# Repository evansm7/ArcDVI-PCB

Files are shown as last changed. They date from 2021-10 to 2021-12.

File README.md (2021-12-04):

# ArcDVI VIDC adapter PCBs
30 November 2021

Two PCBs used in the [ArcDVI](https://github.com/evansm7/ArcDVI) project.

These PCBs (#1 and #2) both perform the task of physical interfacing to an Acorn Archimedes VIDC chip, but for different machines.  PCB #1 is an interposer for VIDC-socketed machines (such as A440), which plugs into the VIDC socket and carries a socket for the VIDC.  PCB #2 uses an upturned through-hole PLCC socket to clip around a soldered VIDC (in machines such as A3000).

[vidc_interposer1 schematic](doc/vidc_interposer1.pdf), [vidc_interposer1 board](doc/vidc_interposer1_brd.pdf), [vidc_interposer2 schematic](doc/vidc_interposer2-PTH.pdf),
[vidc_interposer2 board](doc/vidc_interposer2-PTH_brd.pdf)

It was originally hoped that PCB #1 could be used on an A3000 too, with an SMT PLCC socket on the bottom (and nothing mounted on the top).  Those sockets are shallow, and the board level is then too low to clear surrounding components.  (Note there are two odd holes in the board; this was to clear some jumper headers.  These were unnecessarily carried into PCB #2's layout too.  In short, neither board needs these holes anymore.)

A separate project (TBD) is recreating PLCC socket-to-socket interface "blocks", enabling a PLCC socket (rather than plug) to be used on the underside of board #1.

The PCBs are designed in Eagle.

Copyright 2021 Matt Evans

CC BY-SA 3.0

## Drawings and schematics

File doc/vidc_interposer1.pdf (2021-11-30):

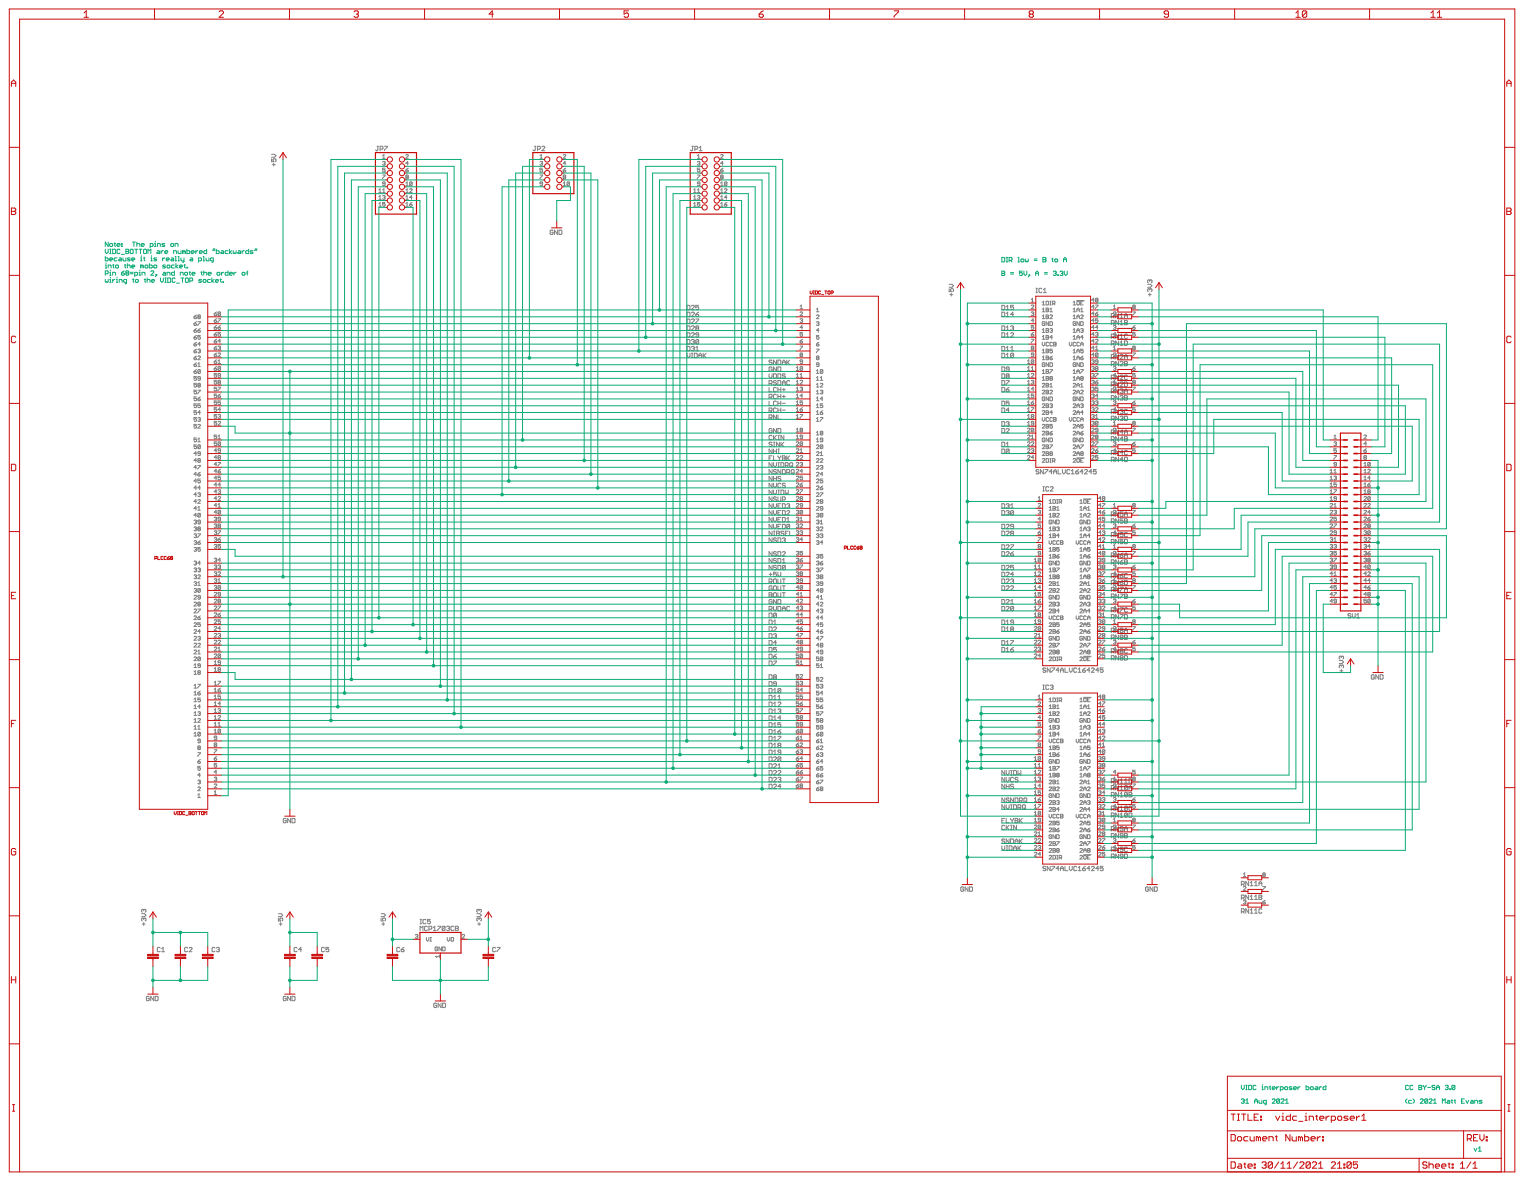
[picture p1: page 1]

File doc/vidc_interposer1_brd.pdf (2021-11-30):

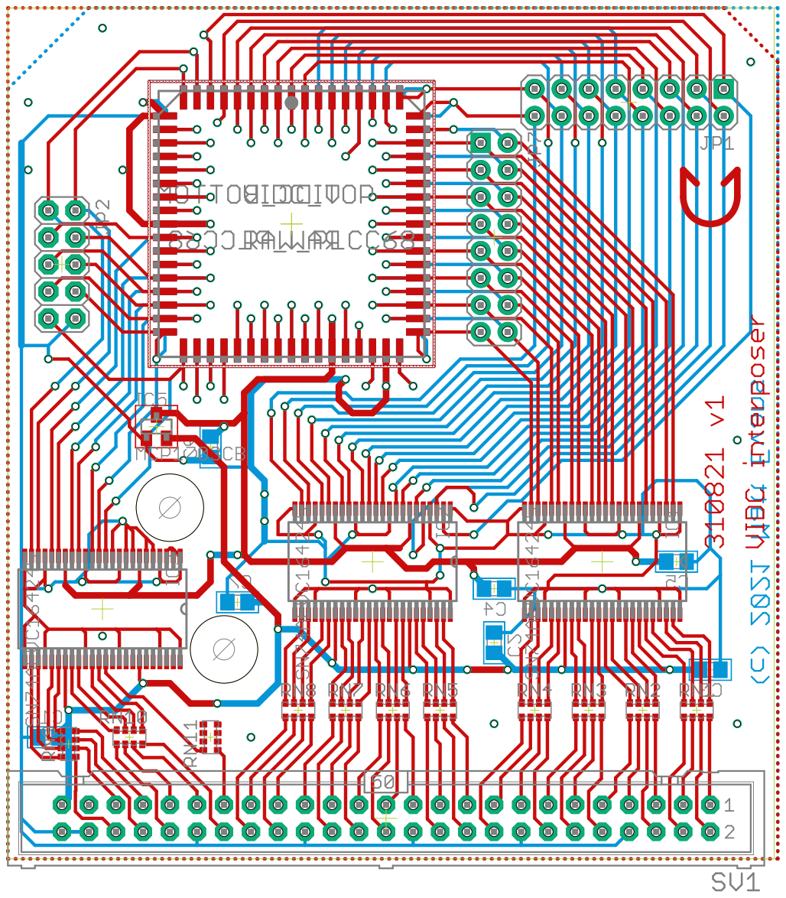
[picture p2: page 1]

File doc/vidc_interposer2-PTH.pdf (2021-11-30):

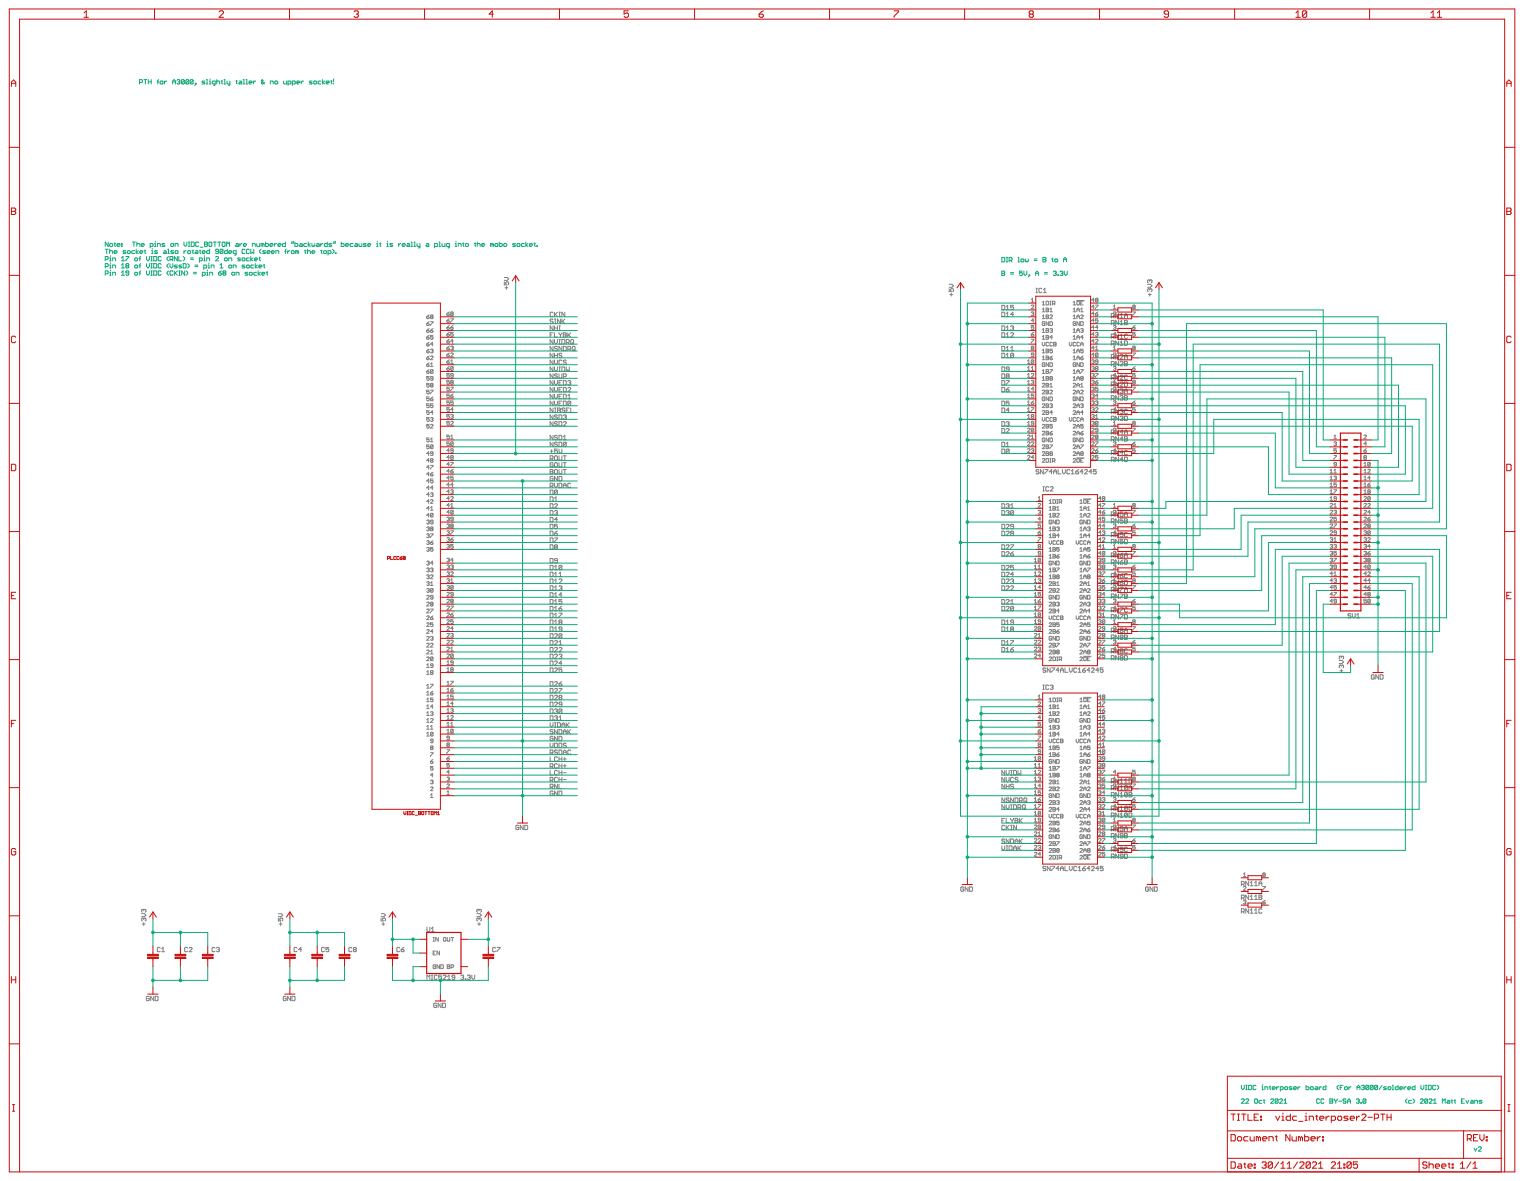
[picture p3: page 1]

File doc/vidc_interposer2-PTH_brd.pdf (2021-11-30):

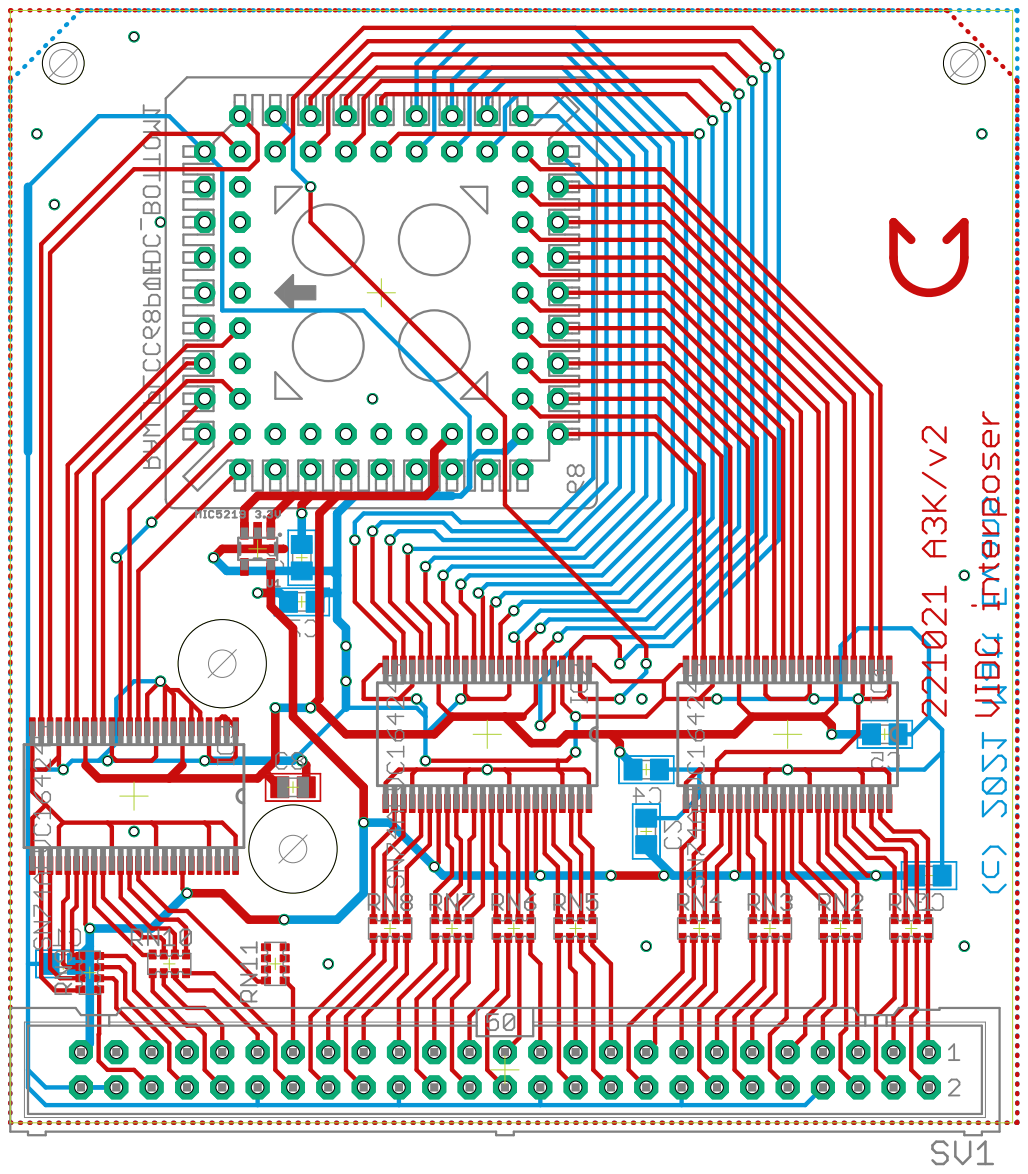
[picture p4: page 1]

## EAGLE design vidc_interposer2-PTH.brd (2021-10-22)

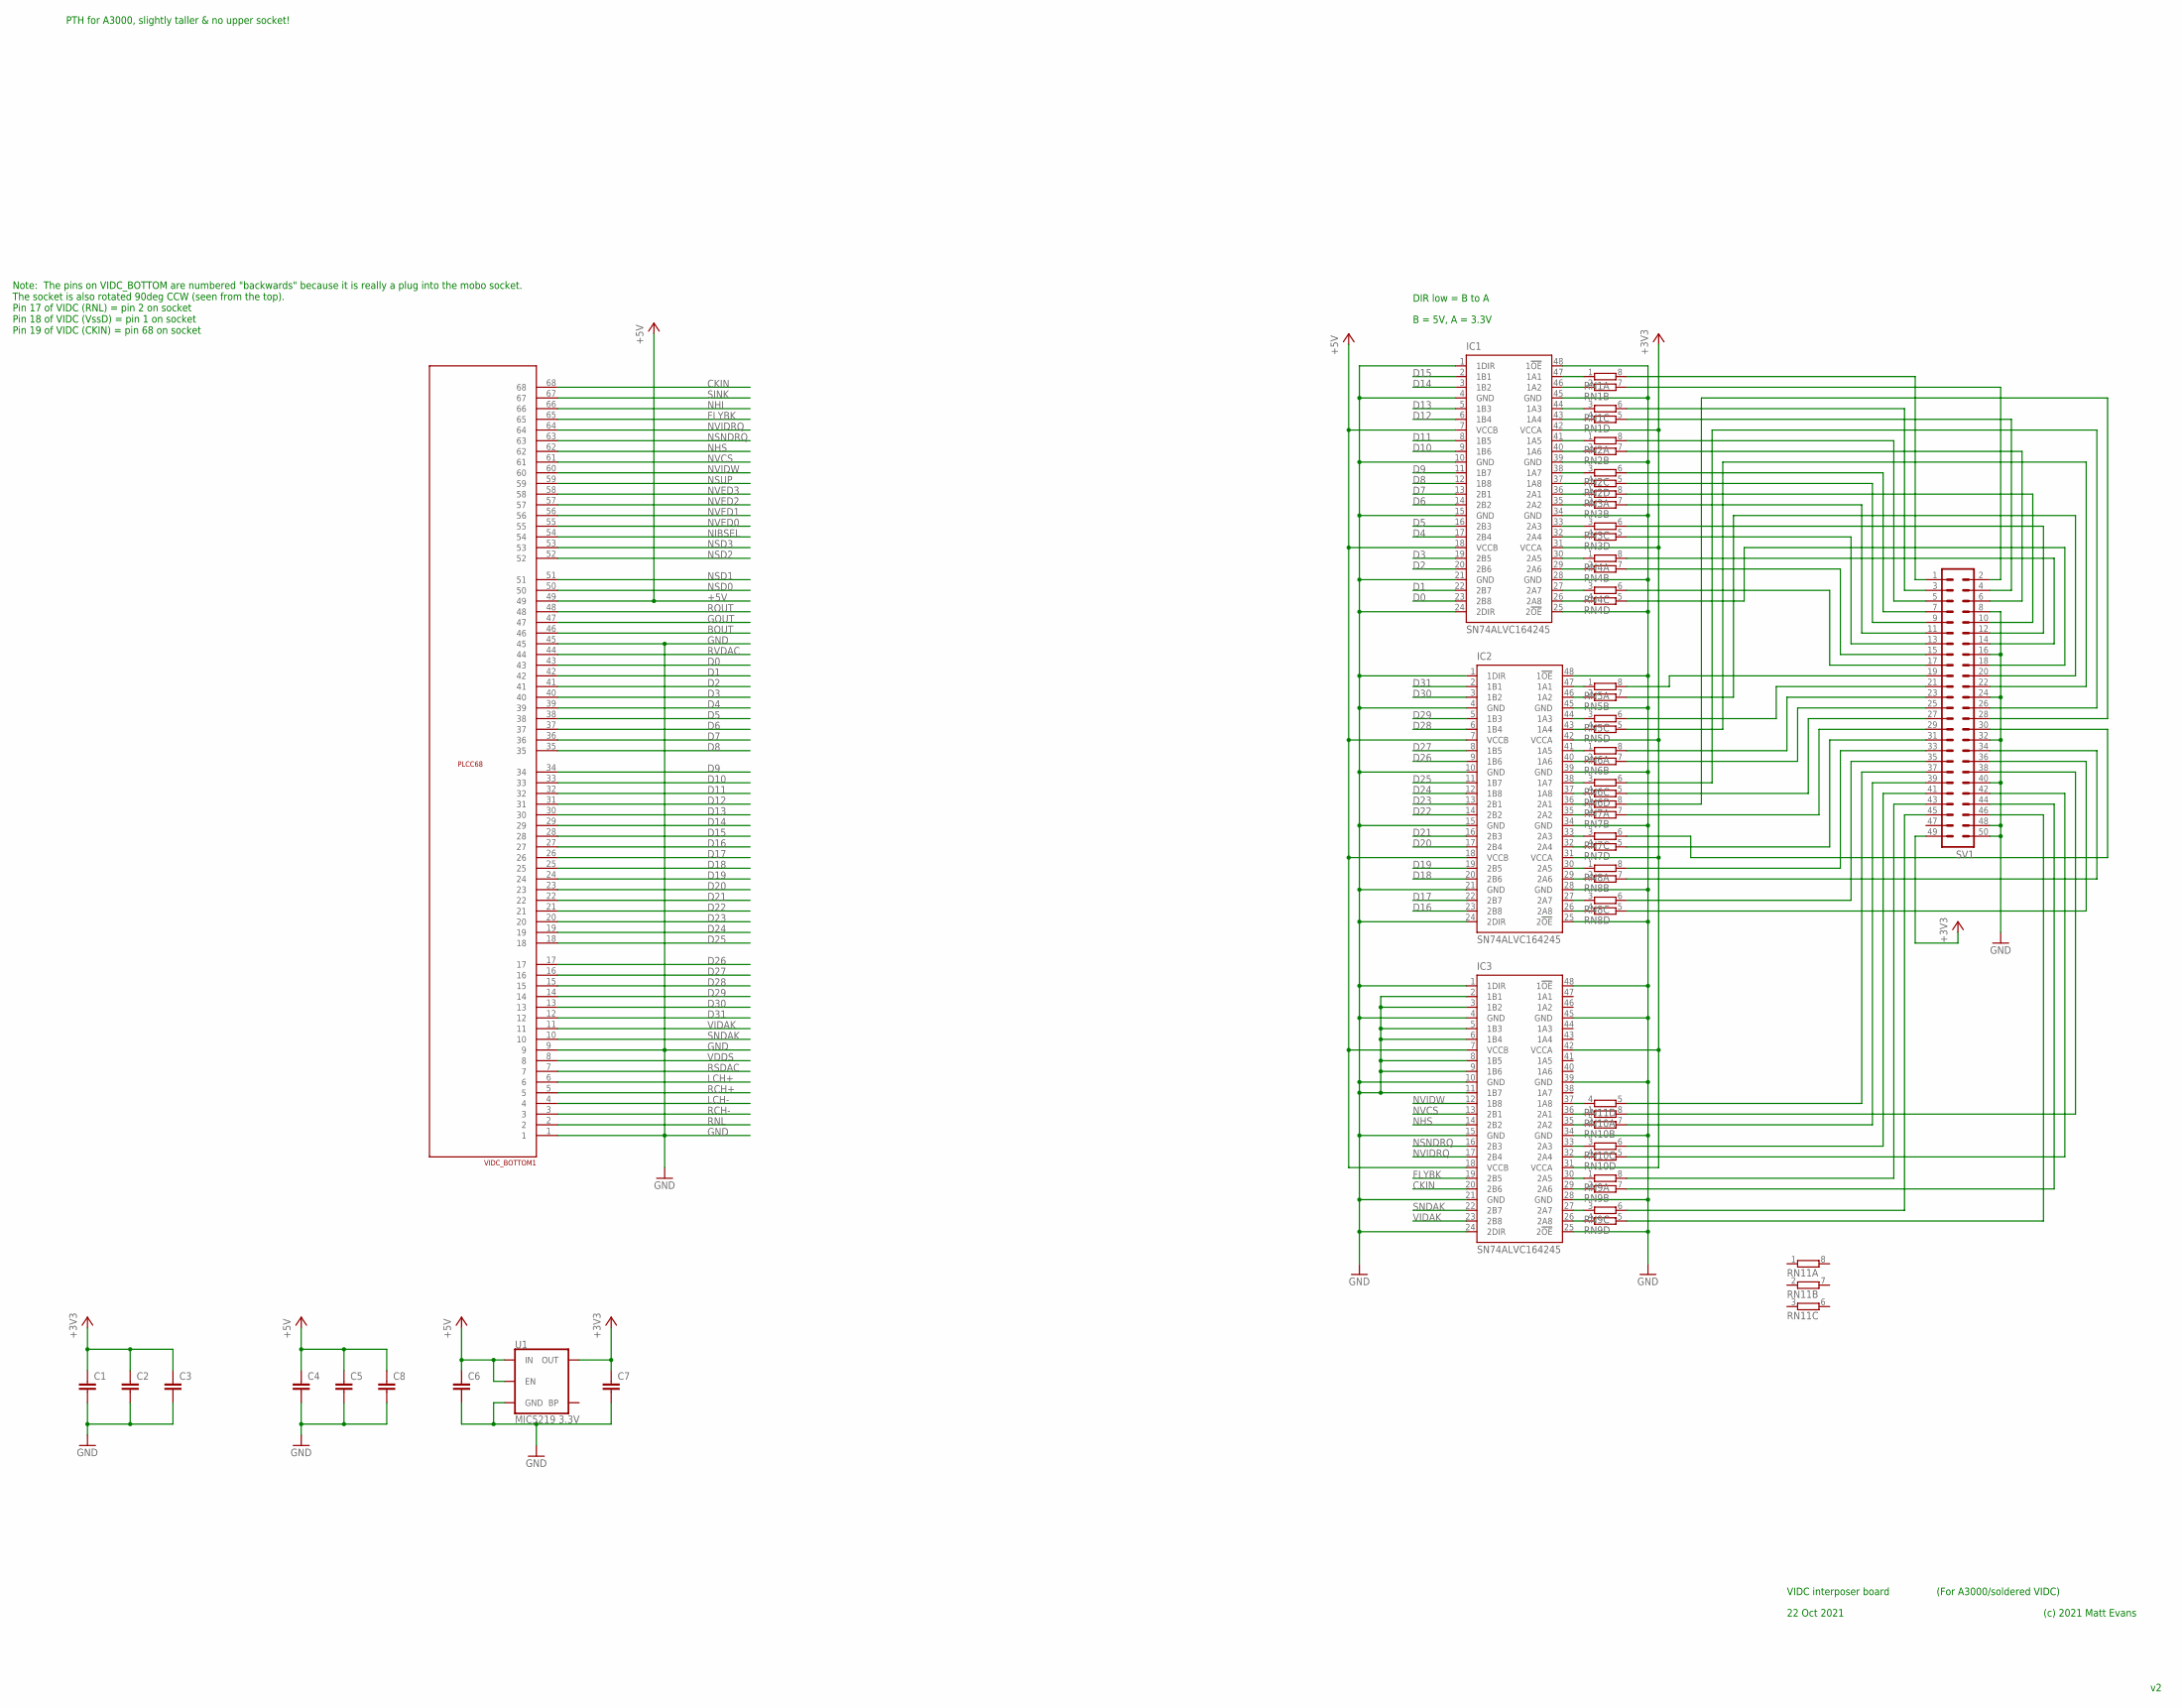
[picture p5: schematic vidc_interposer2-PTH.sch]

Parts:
C1, C2, C3, C4, C5, C6, C7, C8: C-EUC0805; C0805
IC1, IC2, IC3: SN74ALVC164245; DL_R-PDSO-G48
RN1, RN2, RN3, RN4, RN5, RN6, RN7, RN8, RN9, RN10, RN11: 4R-NCAY16; CAY16
SV1: ML50
U1: MIC5219 3.3V; SOT23-5
VIDC_BOTTOM1: RAW_PLCC68PTH; S68

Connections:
+3V3: C1.1, C2.1, C3.1, C7.1, IC1.31 (VCCA), IC1.42 (VCCA), IC2.31 (VCCA), IC2.42 (VCCA), IC3.31 (VCCA), IC3.42 (VCCA), SV1.49, U1.5 (OUT)
+5V: C4.1, C5.1, C6.1, C8.1, IC1.7 (VCCB), IC1.18 (VCCB), IC2.7 (VCCB), IC2.18 (VCCB), IC3.7 (VCCB), IC3.18 (VCCB), U1.1 (IN), U1.3 (EN), VIDC_BOTTOM1.49
BOUT: VIDC_BOTTOM1.46
CKIN: IC3.20 (2B6), VIDC_BOTTOM1.68
D0: IC1.23 (2B8), VIDC_BOTTOM1.43
D1: IC1.22 (2B7), VIDC_BOTTOM1.42
D2: IC1.20 (2B6), VIDC_BOTTOM1.41
D3: IC1.19 (2B5), VIDC_BOTTOM1.40
D4: IC1.17 (2B4), VIDC_BOTTOM1.39
D5: IC1.16 (2B3), VIDC_BOTTOM1.38
D6: IC1.14 (2B2), VIDC_BOTTOM1.37
D7: IC1.13 (2B1), VIDC_BOTTOM1.36
D8: IC1.12 (1B8), VIDC_BOTTOM1.35
D9: IC1.11 (1B7), VIDC_BOTTOM1.34
D10: IC1.9 (1B6), VIDC_BOTTOM1.33
D11: IC1.8 (1B5), VIDC_BOTTOM1.32
D12: IC1.6 (1B4), VIDC_BOTTOM1.31
D13: IC1.5 (1B3), VIDC_BOTTOM1.30
D14: IC1.3 (1B2), VIDC_BOTTOM1.29
D15: IC1.2 (1B1), VIDC_BOTTOM1.28
D16: IC2.23 (2B8), VIDC_BOTTOM1.27
D17: IC2.22 (2B7), VIDC_BOTTOM1.26
D18: IC2.20 (2B6), VIDC_BOTTOM1.25
D19: IC2.19 (2B5), VIDC_BOTTOM1.24
D20: IC2.17 (2B4), VIDC_BOTTOM1.23
D21: IC2.16 (2B3), VIDC_BOTTOM1.22
D22: IC2.14 (2B2), VIDC_BOTTOM1.21
D23: IC2.13 (2B1), VIDC_BOTTOM1.20
D24: IC2.12 (1B8), VIDC_BOTTOM1.19
D25: IC2.11 (1B7), VIDC_BOTTOM1.18
D26: IC2.9 (1B6), VIDC_BOTTOM1.17
D27: IC2.8 (1B5), VIDC_BOTTOM1.16
D28: IC2.6 (1B4), VIDC_BOTTOM1.15
D29: IC2.5 (1B3), VIDC_BOTTOM1.14
D30: IC2.3 (1B2), VIDC_BOTTOM1.13
D31: IC2.2 (1B1), VIDC_BOTTOM1.12
FLYBK: IC3.19 (2B5), VIDC_BOTTOM1.65
GND: C1.2, C2.2, C3.2, C4.2, C5.2, C6.2, C7.2, C8.2, IC1.1 (1DIR), IC1.4 (GND), IC1.10 (GND), IC1.15 (GND), IC1.21 (GND), IC1.24 (2DIR), IC1.25 (2!OE), IC1.28 (GND), IC1.34 (GND), IC1.39 (GND), IC1.45 (GND), IC1.48 (1!OE), IC2.1 (1DIR), IC2.4 (GND), IC2.10 (GND), IC2.15 (GND), IC2.21 (GND), IC2.24 (2DIR), IC2.25 (2!OE), IC2.28 (GND), IC2.34 (GND), IC2.39 (GND), IC2.45 (GND), IC2.48 (1!OE), IC3.1 (1DIR), IC3.2 (1B1), IC3.3 (1B2), IC3.4 (GND), IC3.5 (1B3), IC3.6 (1B4), IC3.8 (1B5), IC3.9 (1B6), IC3.10 (GND), IC3.11 (1B7), IC3.15 (GND), IC3.21 (GND), IC3.24 (2DIR), IC3.25 (2!OE), IC3.28 (GND), IC3.34 (GND), IC3.39 (GND), IC3.45 (GND), IC3.48 (1!OE), SV1.8, SV1.16, SV1.24, SV1.32, SV1.40, SV1.48, SV1.50, U1.2 (GND), VIDC_BOTTOM1.1, VIDC_BOTTOM1.9, VIDC_BOTTOM1.45
GOUT: VIDC_BOTTOM1.47
LCH+: VIDC_BOTTOM1.6
LCH-: VIDC_BOTTOM1.4
unnamed: IC3.26 (2A8), RN9.4 (1)
unnamed: IC3.27 (2A7), RN9.3 (1)
unnamed: IC3.29 (2A6), RN9.2 (1)
unnamed: IC3.30 (2A5), RN9.1
unnamed: IC3.32 (2A4), RN10.4 (1)
unnamed: IC3.33 (2A3), RN10.3 (1)
unnamed: IC3.35 (2A2), RN10.2 (1)
unnamed: IC3.36 (2A1), RN10.1
unnamed: IC1.47 (1A1), RN1.1
unnamed: IC1.46 (1A2), RN1.2 (1)
unnamed: IC1.44 (1A3), RN1.3 (1)
unnamed: IC1.43 (1A4), RN1.4 (1)
unnamed: IC1.41 (1A5), RN2.1
unnamed: IC1.40 (1A6), RN2.2 (1)
unnamed: IC1.38 (1A7), RN2.3 (1)
unnamed: IC1.37 (1A8), RN2.4 (1)
unnamed: IC1.36 (2A1), RN3.1
unnamed: IC1.35 (2A2), RN3.2 (1)
unnamed: IC1.33 (2A3), RN3.3 (1)
unnamed: IC1.32 (2A4), RN3.4 (1)
unnamed: IC1.30 (2A5), RN4.1
unnamed: IC1.29 (2A6), RN4.2 (1)
unnamed: IC3.37 (1A8), RN11.4 (1)
unnamed: IC1.27 (2A7), RN4.3 (1)
unnamed: IC1.26 (2A8), RN4.4 (1)
unnamed: IC2.47 (1A1), RN5.1
unnamed: IC2.46 (1A2), RN5.2 (1)
unnamed: IC2.44 (1A3), RN5.3 (1)
unnamed: IC2.43 (1A4), RN5.4 (1)
unnamed: IC2.41 (1A5), RN6.1
unnamed: IC2.40 (1A6), RN6.2 (1)
unnamed: IC2.38 (1A7), RN6.3 (1)
unnamed: IC2.37 (1A8), RN6.4 (1)
unnamed: IC2.36 (2A1), RN7.1
unnamed: IC2.35 (2A2), RN7.2 (1)
unnamed: IC2.33 (2A3), RN7.3 (1)
unnamed: IC2.32 (2A4), RN7.4 (1)
unnamed: IC2.30 (2A5), RN8.1
unnamed: IC2.29 (2A6), RN8.2 (1)
unnamed: IC2.27 (2A7), RN8.3 (1)
unnamed: IC2.26 (2A8), RN8.4 (1)
unnamed: RN1.8 (2), SV1.1
unnamed: RN1.7 (2), SV1.2
unnamed: RN1.6 (2), SV1.3
unnamed: RN1.5 (2), SV1.4
unnamed: RN5.8 (2), SV1.19
unnamed: RN2.8 (2), SV1.5
unnamed: RN2.7 (2), SV1.6
unnamed: RN2.6 (2), SV1.7
unnamed: RN2.5 (2), SV1.9
unnamed: RN3.7 (2), SV1.11
unnamed: RN5.7 (2), SV1.20
unnamed: RN3.8 (2), SV1.10
unnamed: RN3.5 (2), SV1.13
unnamed: RN3.6 (2), SV1.12
unnamed: RN4.7 (2), SV1.15
unnamed: RN4.8 (2), SV1.14
unnamed: RN4.6 (2), SV1.17
unnamed: RN5.5 (2), SV1.22
unnamed: RN5.6 (2), SV1.21
unnamed: RN4.5 (2), SV1.18
unnamed: RN8.5 (2), SV1.36
unnamed: RN10.8 (2), SV1.38
unnamed: RN6.6 (2), SV1.26
unnamed: RN6.8 (2), SV1.23
unnamed: RN7.8 (2), SV1.28
unnamed: RN6.7 (2), SV1.25
unnamed: RN11.5 (2), SV1.37
unnamed: RN10.5 (2), SV1.42
unnamed: RN6.5 (2), SV1.27
unnamed: RN10.7 (2), SV1.39
unnamed: RN9.7 (2), SV1.44
unnamed: RN9.8 (2), SV1.43
unnamed: RN7.7 (2), SV1.29
unnamed: RN9.6 (2), SV1.45
unnamed: RN7.6 (2), SV1.30
unnamed: RN8.7 (2), SV1.34
unnamed: RN10.6 (2), SV1.41
unnamed: RN7.5 (2), SV1.31
unnamed: RN8.8 (2), SV1.33
unnamed: RN8.6 (2), SV1.35
unnamed: RN9.5 (2), SV1.46
NHI: VIDC_BOTTOM1.66
NHS: IC3.14 (2B2), VIDC_BOTTOM1.62
NIBSEL: VIDC_BOTTOM1.54
NSD0: VIDC_BOTTOM1.50
NSD1: VIDC_BOTTOM1.51
NSD2: VIDC_BOTTOM1.52
NSD3: VIDC_BOTTOM1.53
NSNDRQ: IC3.16 (2B3), VIDC_BOTTOM1.63
NSUP: VIDC_BOTTOM1.59
NVCS: IC3.13 (2B1), VIDC_BOTTOM1.61
NVED0: VIDC_BOTTOM1.55
NVED1: VIDC_BOTTOM1.56
NVED2: VIDC_BOTTOM1.57
NVED3: VIDC_BOTTOM1.58
NVIDRQ: IC3.17 (2B4), VIDC_BOTTOM1.64
NVIDW: IC3.12 (1B8), VIDC_BOTTOM1.60
RCH+: VIDC_BOTTOM1.5
RCH-: VIDC_BOTTOM1.3
RNL: VIDC_BOTTOM1.2
ROUT: VIDC_BOTTOM1.48
RSDAC: VIDC_BOTTOM1.7
RVDAC: VIDC_BOTTOM1.44
SINK: VIDC_BOTTOM1.67
SNDAK: IC3.22 (2B7), VIDC_BOTTOM1.10
VDDS: VIDC_BOTTOM1.8
VIDAK: IC3.23 (2B8), VIDC_BOTTOM1.11

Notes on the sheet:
Note: The pins on VIDC_BOTTOM are numbered "backwards" because it is really a plug into the mobo socket. The socket is also rotated 90deg CCW (seen from the top). Pin 17 of VIDC (RNL) = pin 2 on socket Pin 18 of VIDC (VssD) = pin 1 on socket Pin 19 of VIDC (CKIN) = pin 68 on socket
DIR low = B to A
B = 5V, A = 3.3V
VIDC interposer board
22 Oct 2021
(c) 2021 Matt Evans
PTH for A3000, slightly taller & no upper socket!
(For A3000/soldered VIDC)

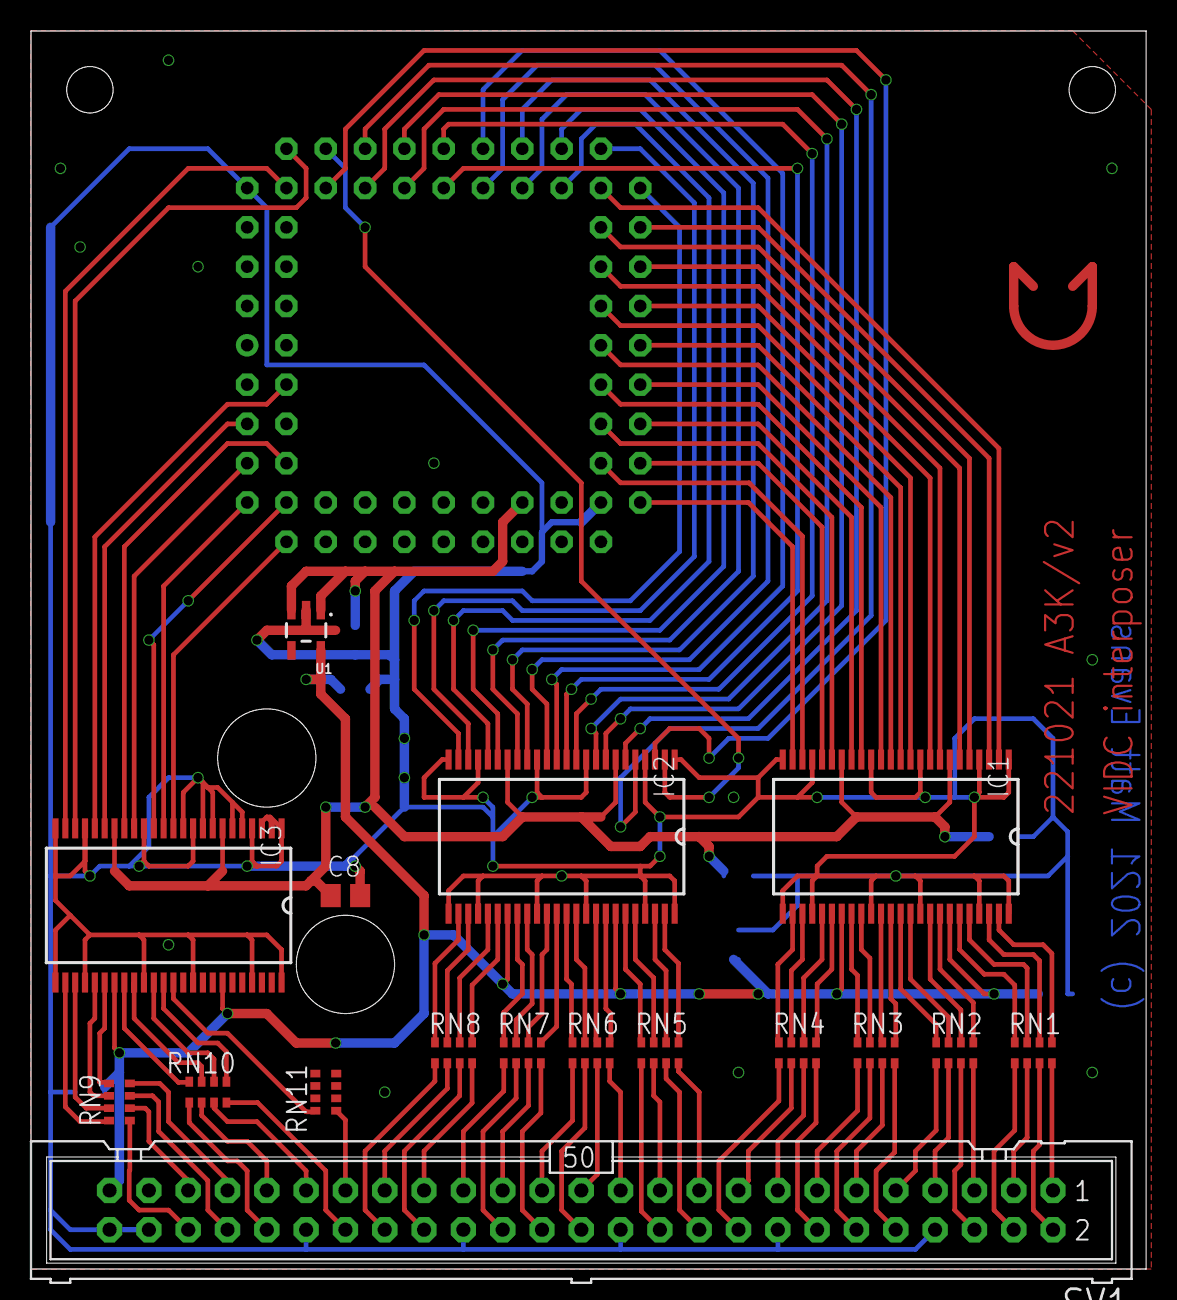
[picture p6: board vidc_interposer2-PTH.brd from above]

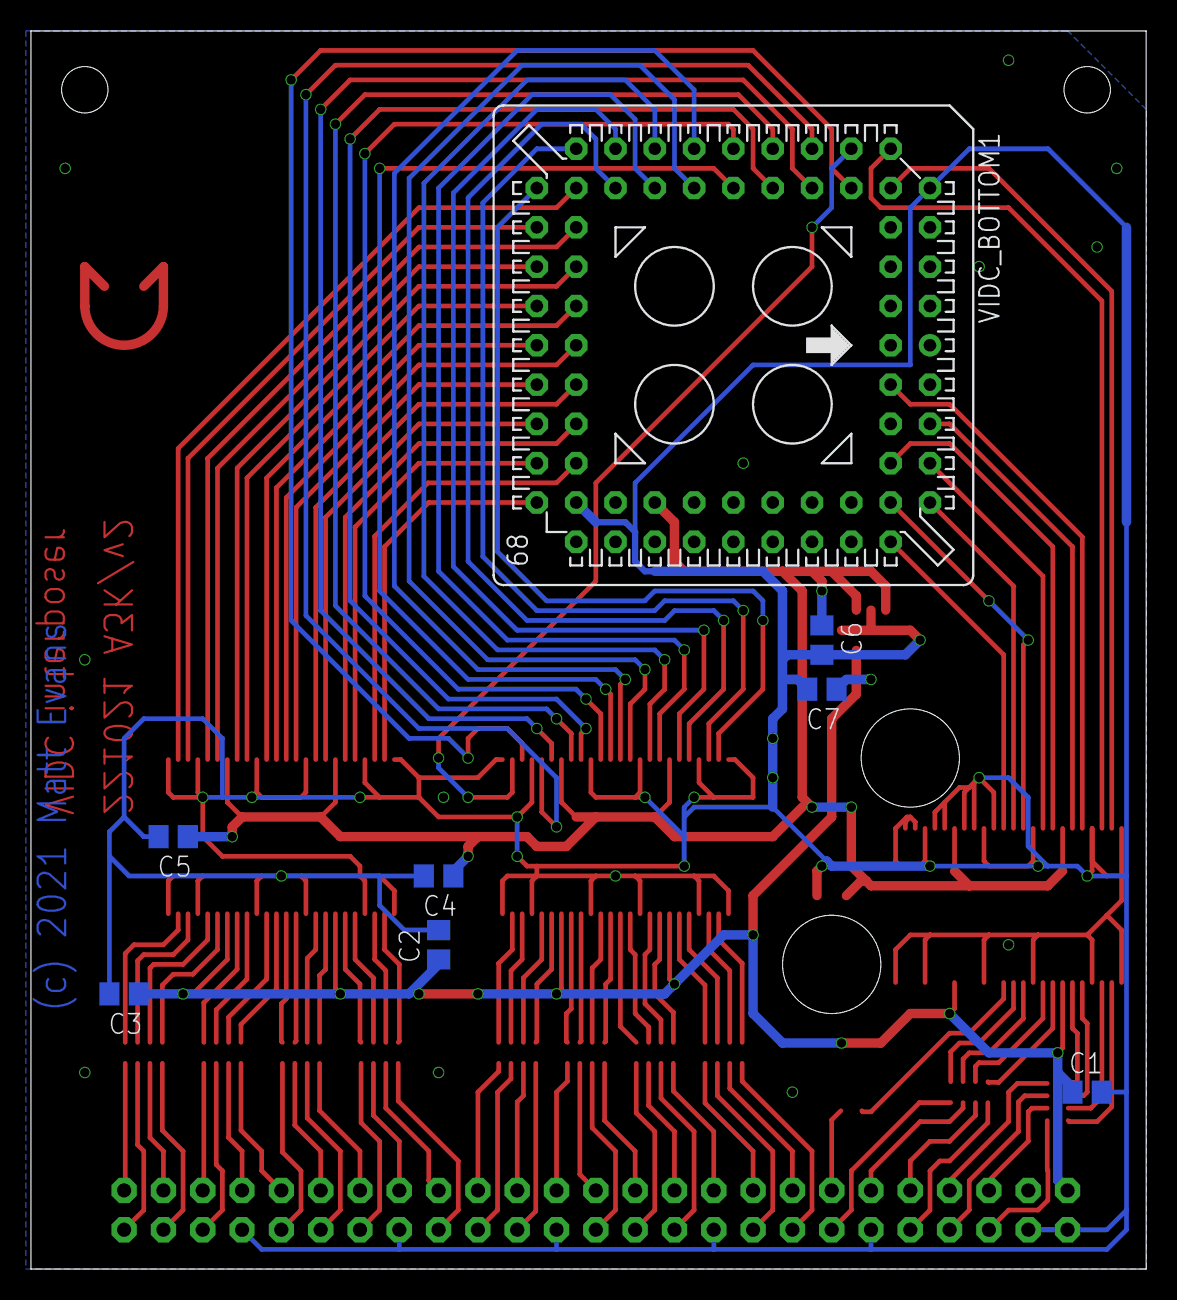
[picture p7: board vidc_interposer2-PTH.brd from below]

Board: 2 copper layers, 72.1 x 80.0 mm, 25 parts (8 on the bottom side), 126 nets.

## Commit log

2021-10-22 Original v1 interposer
    [vidc_interposer1.brd, vidc_interposer1.sch]
2021-10-22 Add A3K/PTH 'v2' board
    [vidc_interposer2-PTH.brd, vidc_interposer2-PTH.sch]
2021-11-30 Update schematics with licence
    [vidc_interposer1.sch, vidc_interposer2-PTH.sch]
2021-11-30 Add schematic/board PDFs

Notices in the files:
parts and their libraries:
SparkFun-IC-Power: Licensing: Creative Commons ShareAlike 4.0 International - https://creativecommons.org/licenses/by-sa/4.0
